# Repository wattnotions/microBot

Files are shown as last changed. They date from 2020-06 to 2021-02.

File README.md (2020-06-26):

# microBot
A tiny robot made using micro stepper motors

Here is a video of the v2 test PCB: 
https://www.youtube.com/watch?v=kQc0UNII-Kc

v3 will run on a 800mAh single cell lipo, esp32, lipo charger, tcrt5000 IR sensor, 2 H-bridge driver chips and a mini USB port
for programming and charging the battery.

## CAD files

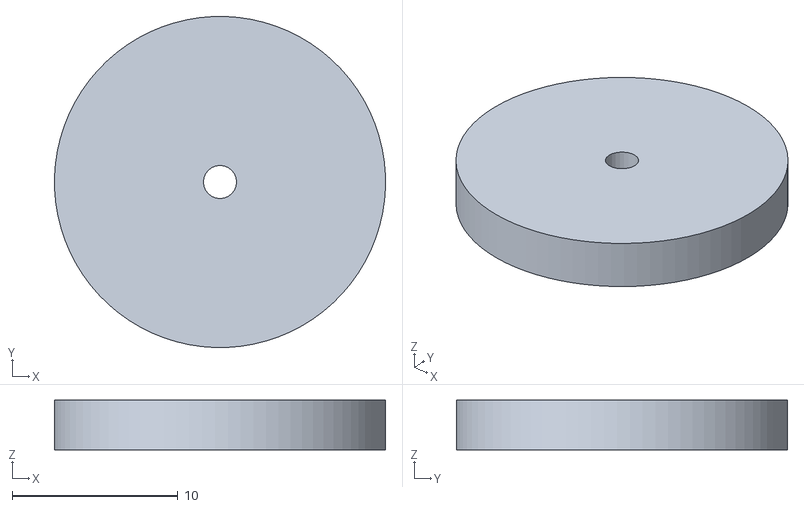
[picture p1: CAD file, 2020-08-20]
CAD_files/wheel.stl
20.0 x 20.0 x 3.00

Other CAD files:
CAD_files/wheel.skp

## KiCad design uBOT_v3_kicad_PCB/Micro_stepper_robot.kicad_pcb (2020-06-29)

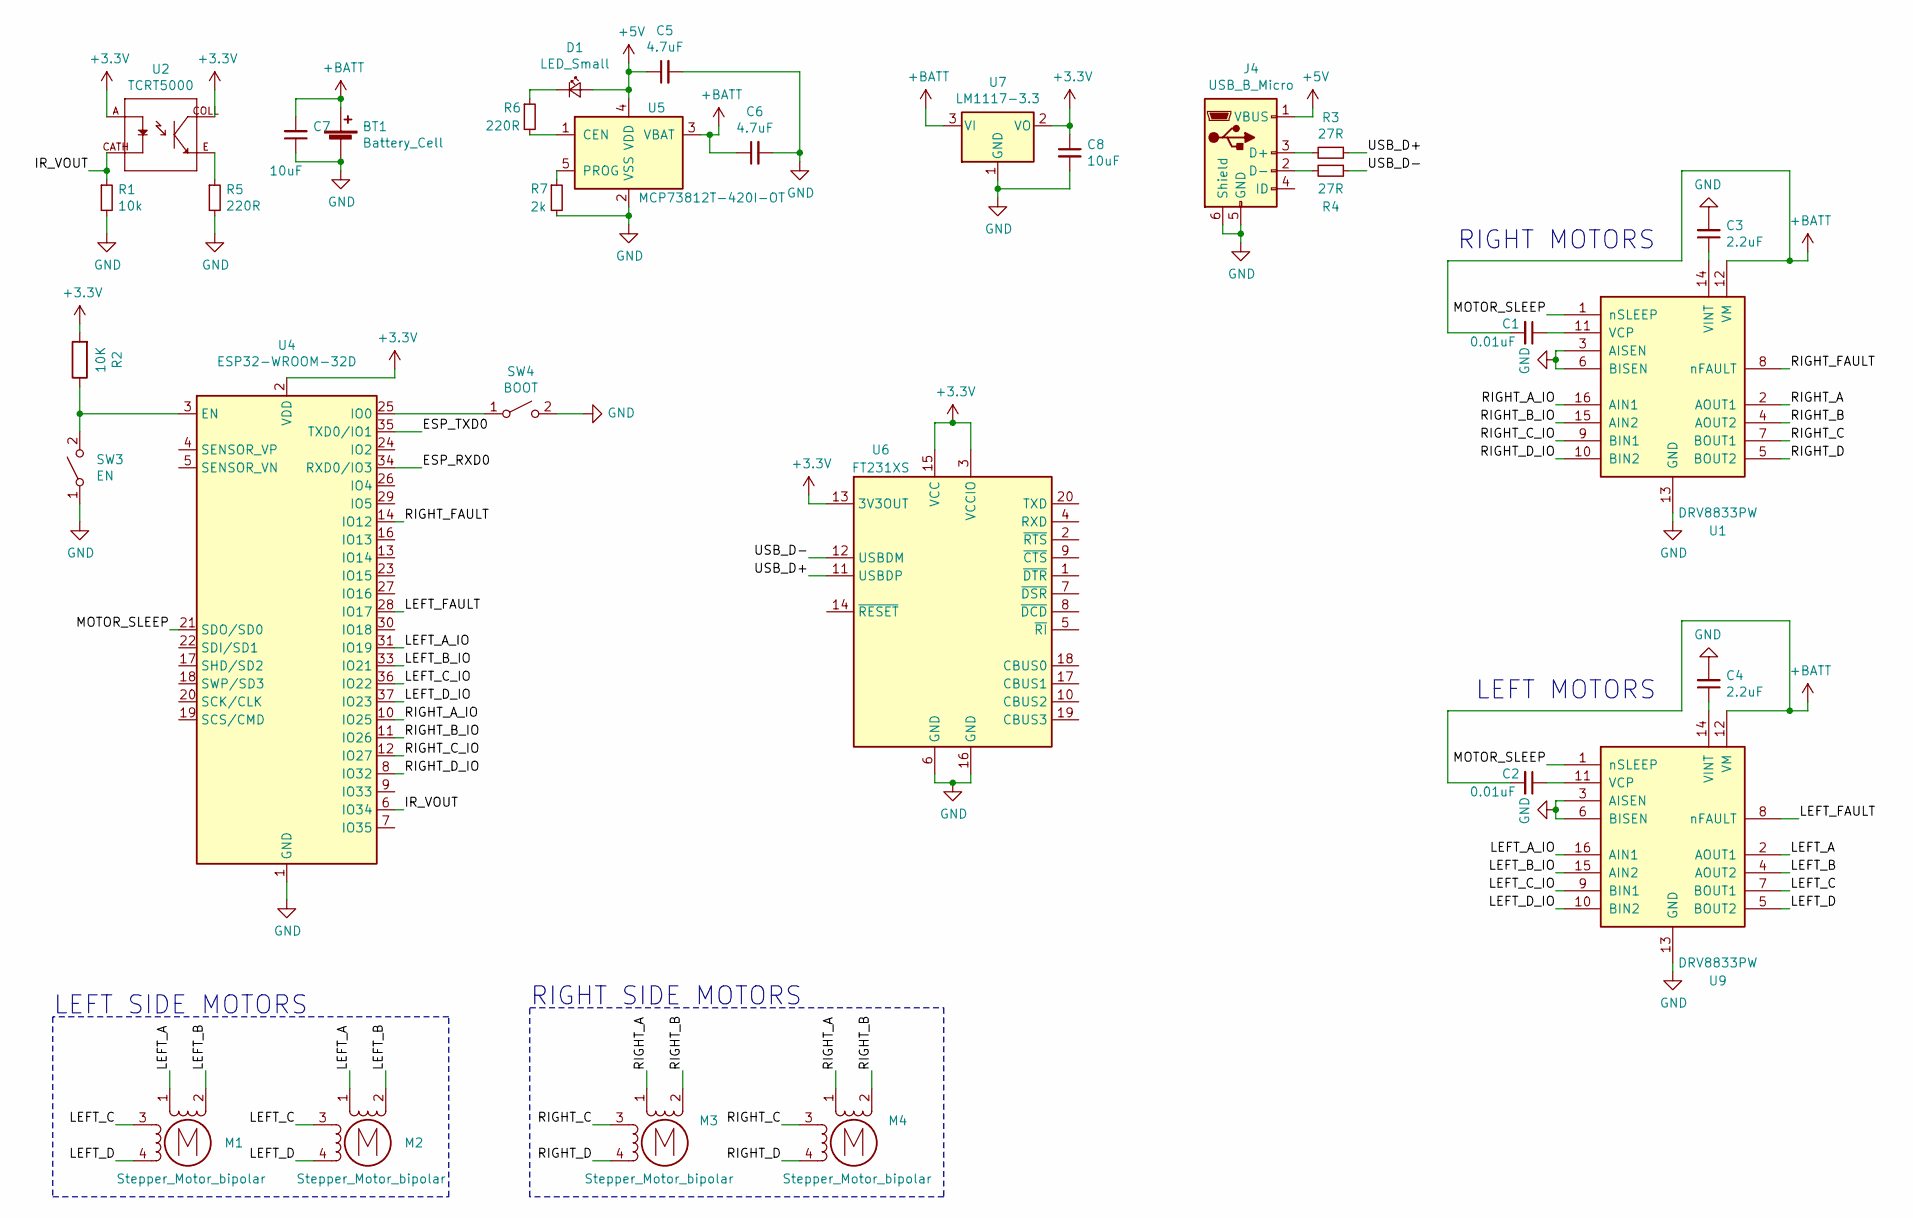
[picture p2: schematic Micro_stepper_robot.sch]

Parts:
BT1: Battery_Cell; Molex_PicoBlade_53398-0271_1x02-1MP_P1.25mm_Vertical
C1, C2: 0.01uF; C_0805_2012Metric_Pad1.15x1.40mm_HandSolder
C3, C4: 2.2uF; C_0805_2012Metric_Pad1.15x1.40mm_HandSolder
C5, C6: 4.7uF; C_0805_2012Metric_Pad1.15x1.40mm_HandSolder
C7, C8: 10uF; C_0805_2012Metric_Pad1.15x1.40mm_HandSolder
D1: LED_Small; LED_0603_1608Metric
J4: USB_B_Micro; USB_Micro-B_Molex-105133-0001
M1, M2, M3, M4: Stepper_Motor_bipolar; micro_stepper1
R1: 10k; R_0805_2012Metric_Pad1.15x1.40mm_HandSolder
R2: 10K; R_0805_2012Metric_Pad1.15x1.40mm_HandSolder
R3, R4: 27R; R_0805_2012Metric_Pad1.15x1.40mm_HandSolder
R5, R6: 220R; R_0805_2012Metric_Pad1.15x1.40mm_HandSolder
R7: 2k; R_0805_2012Metric_Pad1.15x1.40mm_HandSolder
SW3: EN; SW_SPST_B3U-1000P
SW4: BOOT; SW_SPST_B3U-1000P
U1, U9: DRV8833PW; TSSOP-16_4.4x5mm_P0.65mm
U2: TCRT5000; OPTO_TCRT5000
U4: ESP32-WROOM-32D; ESP32-WROOM-32
U5: MCP73812T-420I-OT; SOT-23-5
U6: FT231XS; SSOP-20_3.9x8.7mm_P0.635mm
U7: LM1117-3.3; SOT-223-3_TabPin2

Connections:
+3V3: C8.1, R2.2, U2.A, U2.COLL, U4.2 (VDD), U6.3 (VCCIO), U6.13 (3V3OUT), U6.15 (VCC), U7.2 (VO)
+5V: C5.1, D1.2 (A), J4.1 (VBUS), U5.4 (VDD)
+BATT: BT1.1 (+), C1.2, C2.2, C6.1, C7.2, U1.12 (VM), U5.3 (VBAT), U7.3 (VI), U9.12 (VM)
/ESP_RXD0: U4.34 (RXD0/IO3)
/ESP_TXD0: U4.35 (TXD0/IO1)
/IR_VOUT: R1.1, U2.CATH, U4.6 (IO34)
/LEFT_A: M1.1, M2.1, U9.2 (AOUT1)
/LEFT_A_IO: U4.31 (IO19), U9.16 (AIN1)
/LEFT_B: M1.2 (-), M2.2 (-), U9.4 (AOUT2)
/LEFT_B_IO: U4.33 (IO21), U9.15 (AIN2)
/LEFT_C: M1.3, M2.3, U9.7 (BOUT1)
/LEFT_C_IO: U4.36 (IO22), U9.9 (BIN1)
/LEFT_D: M1.4, M2.4, U9.5 (BOUT2)
/LEFT_D_IO: U4.37 (IO23), U9.10 (BIN2)
/LEFT_FAULT: U4.28 (IO17), U9.8 (nFAULT)
/MOTOR_SLEEP: U1.1 (nSLEEP), U4.21 (SDO/SD0), U9.1 (nSLEEP)
/RIGHT_A: M3.1, M4.1, U1.2 (AOUT1)
/RIGHT_A_IO: U1.16 (AIN1), U4.10 (IO25)
/RIGHT_B: M3.2 (-), M4.2 (-), U1.4 (AOUT2)
/RIGHT_B_IO: U1.15 (AIN2), U4.11 (IO26)
/RIGHT_C: M3.3, M4.3, U1.7 (BOUT1)
/RIGHT_C_IO: U1.9 (BIN1), U4.12 (IO27)
/RIGHT_D: M3.4, M4.4, U1.5 (BOUT2)
/RIGHT_D_IO: U1.10 (BIN2), U4.8 (IO32)
/RIGHT_FAULT: U1.8 (nFAULT), U4.14 (IO12)
/USB_D+: R3.1, U6.11 (USBDP)
/USB_D-: R4.1, U6.12 (USBDM)
GND: BT1.2 (-), C3.2, C4.2, C5.2, C6.2, C7.1, C8.2, J4.5 (GND), J4.6 (Shield), R1.2, R5.2, R7.2, SW3.1 (A), SW4.2 (B), U1.3 (AISEN), U1.6 (BISEN), U1.13 (GND), U4.1 (GND), U4.15 (GND), U4.38 (GND), U4.39 (GND), U5.2 (VSS), U6.6 (GND), U6.16 (GND), U7.1 (GND), U9.3 (AISEN), U9.6 (BISEN), U9.13 (GND)
unnamed: C1.1, U1.11 (VCP)
unnamed: C2.1, U9.11 (VCP)
unnamed: C3.1, U1.14 (VINT)
unnamed: C4.1, U9.14 (VINT)
unnamed: D1.1 (K), R6.1
unnamed: J4.2 (D-), R4.2
unnamed: J4.3 (D+), R3.2
unnamed: R2.1, SW3.2 (B), U4.3 (EN)
unnamed: R5.1, U2.E
unnamed: R6.2, U5.1 (CEN)
unnamed: R7.1, U5.5 (PROG)
unnamed: SW4.1 (A), U4.25 (IO0)

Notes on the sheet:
LEFT MOTORS
RIGHT MOTORS
LEFT SIDE MOTORS
RIGHT SIDE MOTORS

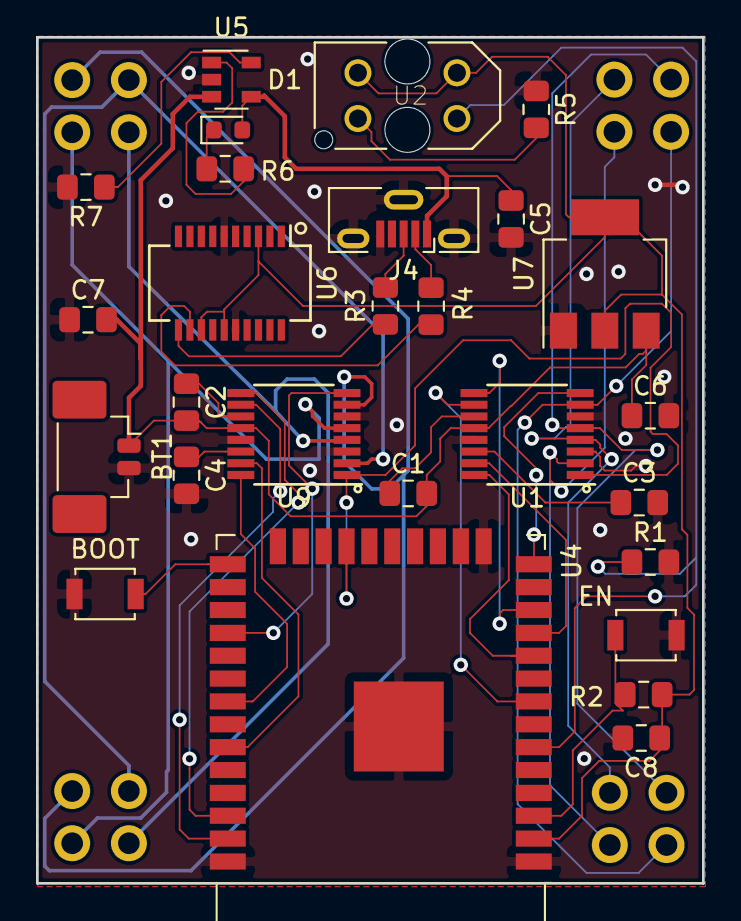
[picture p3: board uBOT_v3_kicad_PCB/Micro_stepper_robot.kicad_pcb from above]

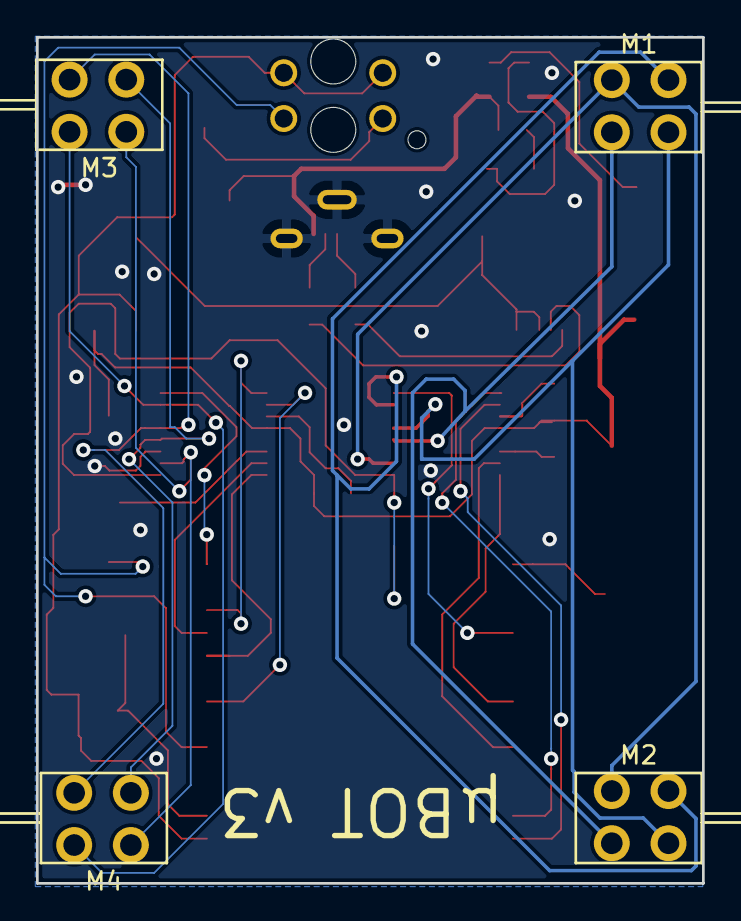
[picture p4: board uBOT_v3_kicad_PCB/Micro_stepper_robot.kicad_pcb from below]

Board: 2 copper layers, 37.0 x 47.0 mm, 31 parts (4 on the bottom side), 38 nets.

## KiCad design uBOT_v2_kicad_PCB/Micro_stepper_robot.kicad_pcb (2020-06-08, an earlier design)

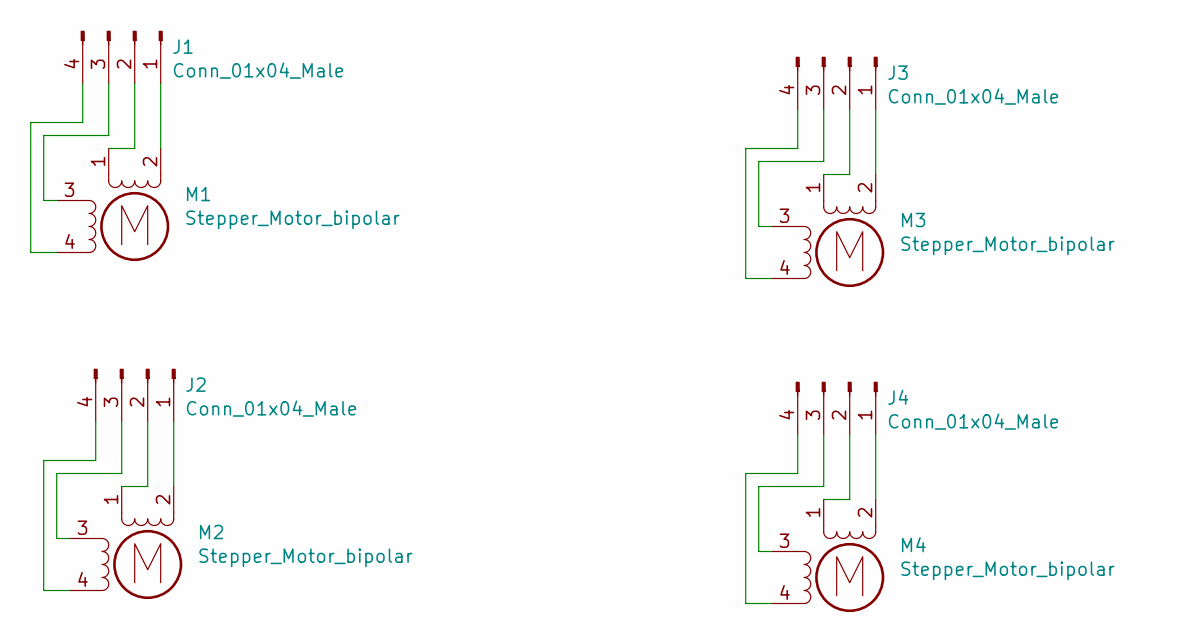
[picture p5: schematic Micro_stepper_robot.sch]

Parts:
J1, J2, J3, J4: Conn_01x04_Male; PinHeader_1x04_P2.54mm_Vertical
M1, M2, M3, M4: Stepper_Motor_bipolar; micro_stepper1

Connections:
unnamed: J1.1, M1.2 (-)
unnamed: J1.2, M1.1
unnamed: J1.3, M1.3
unnamed: J1.4, M1.4
unnamed: J2.1, M2.2 (-)
unnamed: J2.2, M2.1
unnamed: J2.3, M2.3
unnamed: J2.4, M2.4
unnamed: J3.1, M3.2 (-)
unnamed: J3.2, M3.1
unnamed: J3.3, M3.3
unnamed: J3.4, M3.4
unnamed: J4.1, M4.2 (-)
unnamed: J4.2, M4.1
unnamed: J4.3, M4.3
unnamed: J4.4, M4.4

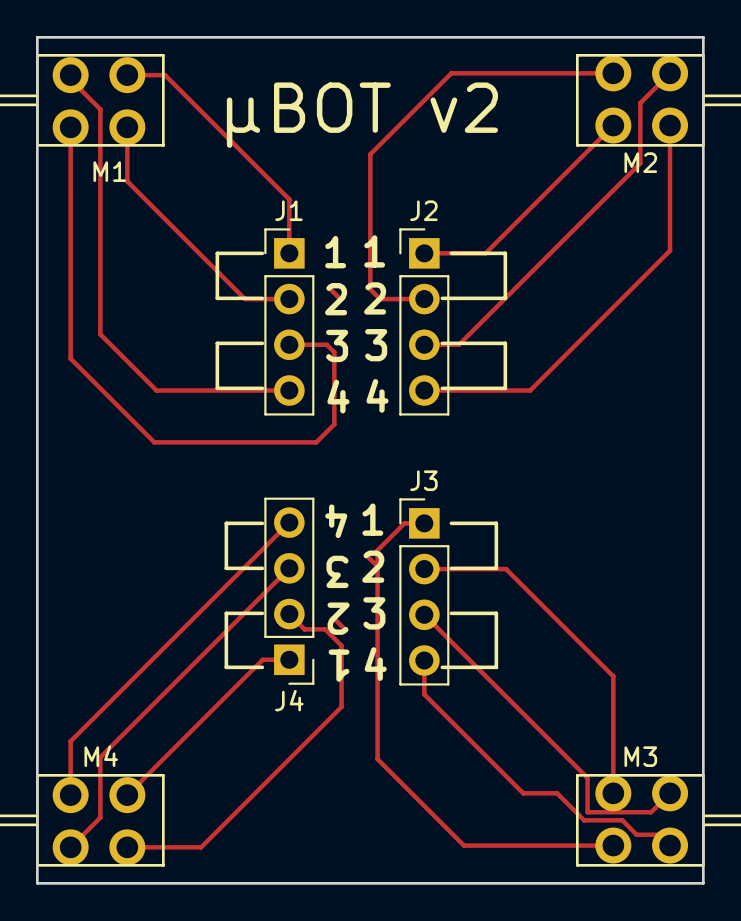
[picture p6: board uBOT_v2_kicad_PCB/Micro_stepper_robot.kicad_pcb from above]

Board: 2 copper layers, 37.0 x 47.0 mm, 8 parts (0 on the bottom side), 16 nets.

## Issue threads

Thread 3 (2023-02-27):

Question

pablogs9, 2023-02-27:
Hey, just a question here. I saw in a video in your web, that you had problem with those micro steppers torque. Did you achieve them to work properly? How much current are you setting for each coil?

I'm working on a project with the very same motors and a Esp32c3 (but still waiting for my H bridges), so I wonder if it is possible to make them move a mini robot of about 100 grams.

Closed 2023-02-27.

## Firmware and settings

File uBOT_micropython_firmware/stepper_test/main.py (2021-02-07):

from machine import Pin
import time


print("IM IN MAIN")



la = 19
lb = 21
lc = 22
ld = 23

ra = 25
rb = 26
rc = 27
rd = 32


#Left side
#A and B are the same coil
left_a = Pin(la, Pin.OUT)    
left_b = Pin(lb, Pin.OUT)   

#C and D are the same coil
left_c = Pin(lc, Pin.OUT)    
left_d = Pin(ld, Pin.OUT)  

#Right side
#A and B are the same coil
right_a = Pin(ra, Pin.OUT)    
right_b = Pin(rb, Pin.OUT)   

#C and D are the same coil
right_c = Pin(rc, Pin.OUT)    
right_d = Pin(rd, Pin.OUT)   




def disable_steppers():
    left_a.value(0)
    left_b.value(0)
    left_c.value(0)
    left_d.value(0)
    
    right_a.value(0)
    right_b.value(0)
    right_c.value(0)
    right_d.value(0)
    print("Steppers disabled")
    
    
r_step_state = 1; 
def right_steppers(dir, msdelay): ##meant to be called in low latency loop
 
  if (r_step_state == 1):
    right_a.value(0)
    right_b.value(1)
    time.sleep_ms(msdelay)
    
  if (r_step_state == 2):
    right_c.value(0)
    right_d.value(1)
    time.sleep_ms(msdelay)
    
  if (r_step_state == 3):
    right_a.value(1)
    right_b.value(0)
    time.sleep_ms(msdelay)
  
  if (r_step_state == 4):
    right_c.value(1)
    right_d.value(0)
    time.sleep_ms(msdelay)
    
  if  (dir == 1) : r_step_state +=1 #going forward
  elif(dir == 0) : r_step_state -=1 #going backwards

l_step_state = 1 
def left_stepper(dir, msdelay):
  
  if (l_step_state == 1):
    left_a.value(0)
    left_b.value(1)
    time.sleep_ms(msdelay)
    
  if (l_step_state == 2):
    left_c.value(0)
    left_d.value(1)
    time.sleep_ms(msdelay)
    
  if (l_step_state == 3):
    left_a.value(1)
    left_b.value(0)
    time.sleep_ms(msdelay)
  
  if (l_step_state == 4):
    left_c.value(1)
    left_d.value(0)
    time.sleep_ms(msdelay)
    
  if  (dir == 1) : l_step_state +=1 #going forward
  elif(dir == 0) : l_step_state -=1 #going backwards

run_time = 0
start_time = time.time()
while (run_time < 10):
    run_time = time.time() - start_time
    left_stepper(1, 200)
    right_stepper(1,200)
from machine import Pin
import time


print("IM IN MAIN")

l_step_state = 1 
r_step_state = 1


la = 19
lb = 21
lc = 22
ld = 23

ra = 25
rb = 26
rc = 27
rd = 32


#Left side
#A and B are the same coil
left_a = Pin(la, Pin.OUT)    
left_b = Pin(lb, Pin.OUT)   

#C and D are the same coil
left_c = Pin(lc, Pin.OUT)    
left_d = Pin(ld, Pin.OUT)  

#Right side
#A and B are the same coil
right_a = Pin(ra, Pin.OUT)    
right_b = Pin(rb, Pin.OUT)   

#C and D are the same coil
right_c = Pin(rc, Pin.OUT)    
right_d = Pin(rd, Pin.OUT)   




def disable_steppers():
    left_a.value(0)
    left_b.value(0)
    left_c.value(0)
    left_d.value(0)
    
    right_a.value(0)
    right_b.value(0)
    right_c.value(0)
    right_d.value(0)
    print("Steppers disabled")
    
    
r_step_state = 1
def right_steppers(dir, msdelay): ##meant to be called in low latency loop
  global r_step_state
  if (r_step_state == 1):
    right_a.value(0)
    right_b.value(1)
    time.sleep_ms(msdelay)
    
  if (r_step_state == 2):
    right_c.value(0)
    right_d.value(1)
    time.sleep_ms(msdelay)
    
  if (r_step_state == 3):
    right_a.value(1)
    right_b.value(0)
    time.sleep_ms(msdelay)
  
  if (r_step_state == 4):
    right_c.value(1)
    right_d.value(0)
    time.sleep_ms(msdelay)
    
  if  (dir == 1) : r_step_state +=1 #going forward
  elif(dir == 0) : r_step_state -=1 #going backwards


def left_steppers(dir, msdelay):
  global l_step_state
  print(l_step_state)
  if (l_step_state == 1):
    
    left_a.value(0)
    left_b.value(1)
    time.sleep_ms(msdelay)
    
  if (l_step_state == 2):
    left_c.value(0)
    left_d.value(1)
    time.sleep_ms(msdelay)
    
  if (l_step_state == 3):
    left_a.value(1)
    left_b.value(0)
    time.sleep_ms(msdelay)
  
  if (l_step_state == 4):
    left_c.value(1)
    left_d.value(0)
    time.sleep_ms(msdelay)
    
  if  (dir == 1) : l_step_state +=1 #going forward
  elif(dir == 0) : l_step_state -=1 #going backwards

run_time = 0
start_time = time.time()
while (run_time < 10):
    run_time = time.time() - start_time
    left_steppers(1, 200)
   # right_steppers(1,200)
   
    
    
    
disable_steppers()
    
    
    
    
    




   
    
    
    
disable_steppers()
    
    
    
    
    

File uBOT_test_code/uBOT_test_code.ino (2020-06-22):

int ms_delay = 100;

// the setup function runs once when you press reset or power the board
void setup() {
  // initialize digital pin LED_BUILTIN as an output.
  pinMode(LED_BUILTIN, OUTPUT);
}

// the loop function runs over and over again forever
void loop() {
  
  digitalWrite(2, LOW);   //step1 
  digitalWrite(3, HIGH);  

  digitalWrite(6, LOW);   
  digitalWrite(7, HIGH);    
  delay(ms_delay);    

  digitalWrite(4, HIGH);  //step1 
  digitalWrite(5, LOW);   

  digitalWrite(8, LOW);   
  digitalWrite(9, HIGH);    
  delay(ms_delay);

  digitalWrite(2, HIGH);   //step 1
  digitalWrite(3, LOW);    

  digitalWrite(6, HIGH);   
  digitalWrite(7, LOW);    
  delay(ms_delay); 

  digitalWrite(4, LOW);   //step 1
  digitalWrite(5, HIGH);  

  digitalWrite(8, HIGH);   
  digitalWrite(9, LOW);    
  delay(ms_delay);
                   
}

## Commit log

2020-03-16 cleaned up silk screen
    [Micro_stepper_robot.kicad_pcb]
2020-06-08 made holes bigger
2020-06-08 updated silkscreen to v2
    [Micro_stepper_robot.kicad_pcb]
2020-06-20 added some stepper test code
2020-06-21 changed dir structure, added v3 kicad project
    [Micro_stepper_robot.kicad_pcb, Micro_stepper_robot.sch]
2020-06-21 started v3 circuit design
    [Micro_stepper_robot.sch]
2020-06-22 added h bridge drivers
    [Micro_stepper_robot.sch]
2020-06-22 progressed schematic
    [Micro_stepper_robot.sch]
2020-06-22 started stepper motor schematic
    [Micro_stepper_robot.sch]
2020-06-22 added tcrt5000
    [Micro_stepper_robot.sch]
2020-06-26 finished assigning footprints, started layout
    [Micro_stepper_robot.sch]
2020-06-26 progressed layout
    [Micro_stepper_robot.kicad_pcb]
2020-06-29 completed rough footprint placement
    [Micro_stepper_robot.sch]
2020-06-29 routing 75% completed
    [Micro_stepper_robot.kicad_pcb]
2020-06-29 routing completed :D
    [Micro_stepper_robot.kicad_pcb, Micro_stepper_robot.sch]
2020-06-29 put v3 silkscreen on botton
2020-06-29 silkscreen text final touch
    [Micro_stepper_robot.kicad_pcb]
2020-06-29 added filter caps to 3.3v and VBAT
    [Micro_stepper_robot.kicad_pcb]
2020-06-29 safety save
    [Micro_stepper_robot.sch]
2020-06-29 fixed silk screen ref values
    [Micro_stepper_robot.kicad_pcb]
2020-07-13 left steppers working
2020-08-20 added wheel cad files
    [wheel.skp, wheel.stl]
2021-02-07 left steppers in progress
2021-02-07 added debug print statements
2021-02-07 Left steppers working!
2021-02-07 added functions for left and right steppers rotation
2021-09-10 ADDED TX AND TX CONNECTIONS TO USB/UART IC
    [Micro_stepper_robot.sch]
